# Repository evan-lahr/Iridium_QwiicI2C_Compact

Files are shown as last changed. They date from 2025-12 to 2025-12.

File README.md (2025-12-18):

Ultra-compact Qwiic (I²C) breakout for the Iridium 9603/9603N satellite modem (e.g., https://www.sparkfun.com/qwiic-iridium-9603n.html
). Built for space-constrained deployments, it integrates I²C control, power regulation, and modem support circuitry in a footprint only slightly larger than the 9603N itself—ideal for embedded field systems.

See the SparkX thread: https://community.sparkfun.com/t/qwiic-iridium-9603n-bom-firmware/67234/8

<p align="center">
  
  
</p>

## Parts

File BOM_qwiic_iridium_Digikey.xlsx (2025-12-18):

Digi-Key: Shopping Cart
Index | Quantity | Part Number | Manufacturer Part Number | Description | Customer Reference | Available | Backorder | Unit Price | Extended Price USD
1 | 1 | 399-C0603C104K5RACTUCT-ND | C0603C104K5RACTU | CAP CER 0.1UF 50V X7R 0603 | C1 | 1 | 0 | 0.08 | 0.08
2 | 1 | 490-6371-1-ND | GRM185R60J225KE26J | CAP CER 2.2UF 6.3V X5R 0603 | C2 | 1 | 0 | 0.21 | 0.21
3 | 3 | 311-1443-1-ND | CC0603KRX5R6BB105 | CAP CER 1UF 10V X5R 0603 | C3,C8,C10 | 3 | 0 | 0.1 | 0.30
4 | 1 | 445-1318-1-ND | C1608X7R1C224K080AC | CAP CER 0.22UF 16V X7R 0603 | C4 | 1 | 0 | 0.1 | 0.10
5 | 2 | 283-HV0810-2R7105-R-ND | HV0810-2R7105-R | CAP 1F -10% +30% 2.7V T/H | C5,C6 | 2 | 0 | 1.64 | 3.28
6 | 1 | 445-175223-1-ND | C1608X5R0J106K080AE | CAP CER 10UF 6.3V X5R 0603 | C7 | 1 | 0 | 0.35 | 0.35
7 | 1 | 490-GRM188R72A103KA01DCT-ND | GRM188R72A103KA01D | CAP CER 10000PF 100V X7R 0603 | C9 | 1 | 0 | 0.1 | 0.10
8 | 3 | 754-APT1608LSYCKCT-ND | APT1608LSYCK | LED YELLOW CLEAR 2SMD | D1,D2,D3 | 3 | 0 | 0.29 | 0.87
9 | 1 | SAM13255CT-ND | SS4-10-3.50-L-D-K-TR | CONN SOCKET 20POS SMD GOLD | J1 | 1 | 0 | 3 | 3.00
10 | 2 | 455-SM04B-SRSS-TBCT-ND | SM04B-SRSS-TB | CONN HEADER SMD R/A 4POS 1MM | J2,J4 | 2 | 0 | 0.5 | 1.00
11 | 1 | H9161-ND | U.FL-R-SMT(01) | CONN U.FL RCPT STR 50 OHM SMD | J7 | 0 | 1 | 1.53 | 1.53
12 | 1 | DMG3414U-7DICT-ND | DMG3414U-7 | MOSFET N-CH 20V 4.2A SOT23-3 | Q1 | 1 | 0 | 0.74 | 0.74
13 | 2 | CR0603AFX-1001EASCT-ND | CR0603AFX-1001EAS | RESA-AS 0603 1K 1% 100MW TC100 | R1,R12 | 2 | 0 | 0.1 | 0.20
14 | 3 | A129692CT-ND | CRGCQ0603F2K2 | RES 2.2K OHM 1% 1/10W 0603 | R2,R3,R13 | 3 | 0 | 0.1 | 0.30
15 | 1 | 311-4.7KGRCT-ND | RC0603JR-074K7L | RES 4.7K OHM 5% 1/10W 0603 | R4 | 1 | 0 | 0.1 | 0.10
16 | 2 | 311-10.0KHRCT-ND | RC0603FR-0710KL | RES 10K OHM 1% 1/10W 0603 | R5,R14 | 2 | 0 | 0.1 | 0.20
17 | 1 | RMCF0603FT12K0CT-ND | RMCF0603FT12K0 | RES 12K OHM 1% 1/10W 0603 | R6 | 1 | 0 | 0.1 | 0.10
18 | 1 | RMCF0603FT30K1CT-ND | RMCF0603FT30K1 | RES 30.1K OHM 1% 1/10W 0603 | R7 | 1 | 0 | 0.1 | 0.10
19 | 1 | RMCF0603FT100KCT-ND | RMCF0603FT100K | RES 100K OHM 1% 1/10W 0603 | R8 | 1 | 0 | 0.1 | 0.10
20 | 1 | 13-RL0603FR-070R012LCT-ND | RL0603FR-070R012L | RES 0.012 OHM 1% 1/10W 0603 | R9 | 1 | 0 | 0.39 | 0.39
21 | 1 | ATTINY841-SSU-ND | ATTINY841-SSU | IC MCU 8BIT 8KB FLASH 14SOIC | U1 | 1 | 0 | 1.33 | 1.33
22 | 1 | 505-LTC3225EDDB#TRMPBFCT-ND | LTC3225EDDB#TRMPBF | IC SUPERCAP CHARGER 150MA 10DFN | u2 | 1 | 0 | 7.89 | 7.89
23 | 1 | ADM4210-1AUJZ-RL7CT-ND | ADM4210-1AUJZ-RL7 | IC HOT SWAP CTRLR GP TSOT6 | U3 | 1 | 0 | 6.84 | 6.84
24 | 2 | P100HCT-ND | ERJ-3EKF1000V | RES SMD 100 OHM 1% 1/10W 0603 | R10,R11 | 2 | 0 | 0.1 | 0.20
25 | 1 | SAM8857-ND | SMA-J-P-H-ST-EM1 | CONN SMA JACK STR 50OHM EDGE MNT | SMA | 0 | 1 | 2.43 | 2.43
26 | 1 | ARF2200-ND | A-1PA-132-025B2 | COAX CBL U.FL AMC-U.FL AMC 0.9" | AMPH_CABLE | 1 | 0 | 6.89 | 6.89
27 | 2 | 732-7103-6-ND | 9774060243R | REFLOW STANDOFF | NA | 1 | 0 | 1.01 | 1.01

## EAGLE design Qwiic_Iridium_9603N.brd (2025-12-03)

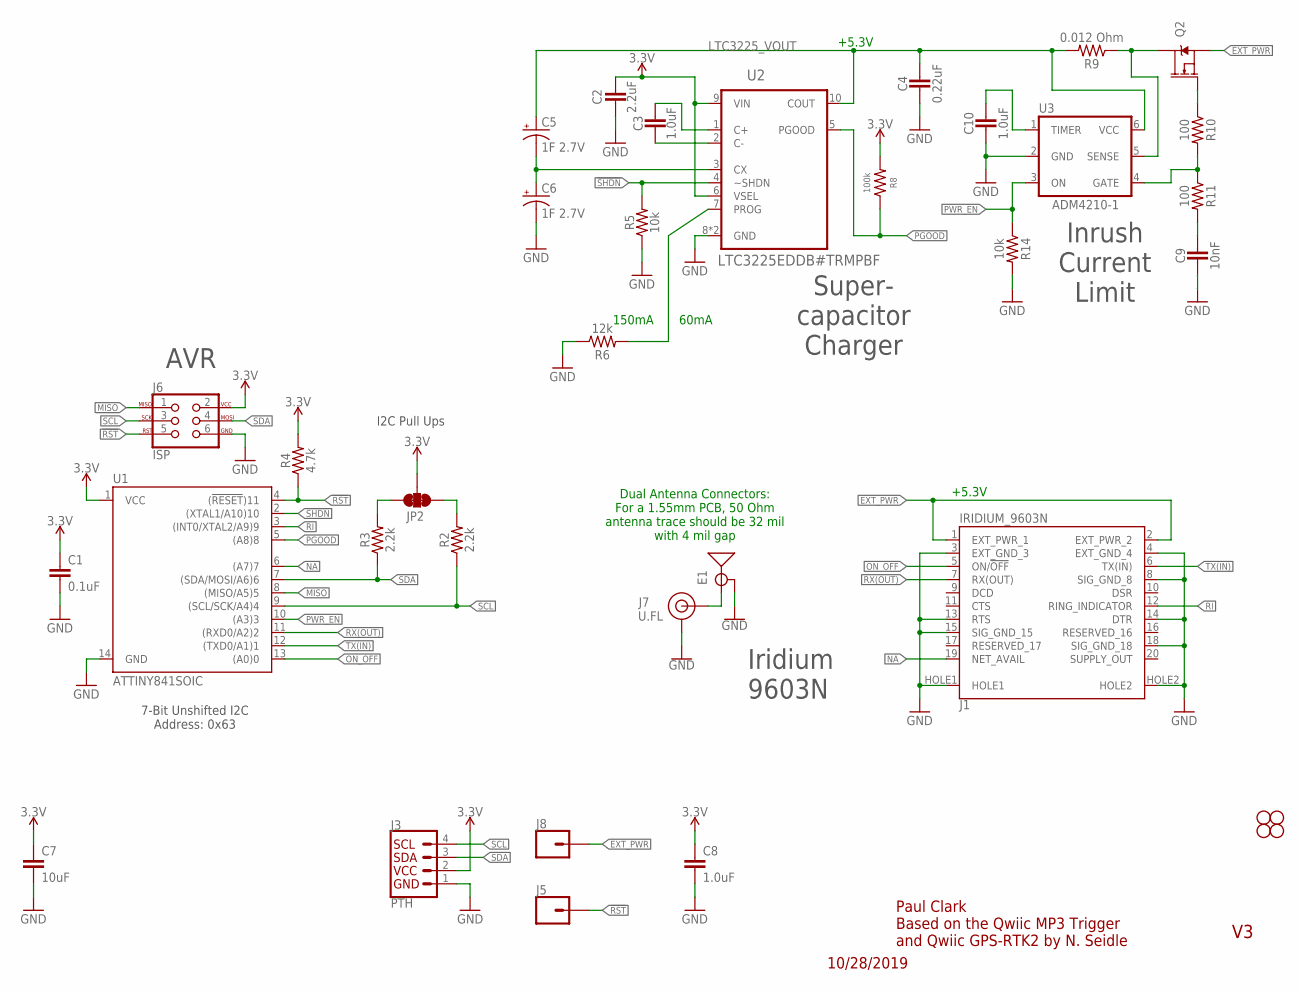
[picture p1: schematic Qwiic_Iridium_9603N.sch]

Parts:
C1: 0.1uF; 0603
C2: 2.2uF; 0603
C3, C8, C10: 1.0uF; 0603
C4: 0.22uF; 0603
C5, C6: 1F 2.7V; CPOL-RADIAL-1F-2.7V
C7: 10uF; 0603
C9: 10nF; 0603
E1: ANTENNA-GROUNDEDEDGE_SMA; SMA-EDGE
J1: IRIDIUM_9603N
J3: PTH; 1X04_1MM_RA
J5, J8: CONN_01PTH_NO_SILK_YES_STOP; 1X01_NO_SILK
J6: ISP; 2X3_TEST_POINTS
J7: U.FL
JP2: JUMPER-SMT_3_2-NC_TRACE_SILK; SMT-JUMPER_3_2-NC_TRACE_SILK
JP3, JP4, JP9, JP10: STAND-OFF
Q2: 5.8A/30V/35mΩ; SOT23-3
R2, R3: 2.2k; 0603
R4: 4.7k; 0603
R5, R14: 10k; 0603
R6: 12k; 0603
R8: 100k; 0603
R9: 0.012 Ohm; 0603
R10, R11: 100; 0603
U1: ATTINY841SOIC; ATTINY841
U2: LTC3225EDDB#TRMPBF; DFN300X200-10L
U3: ADM4210-1; TSOT6

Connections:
3.3V: C1.1, C2.1, C7.1, C8.1, J3.2 (VCC), J6.2, JP2.2, R4.2, R8.2, U1.1 (VCC), U2.6 (VSEL), U2.9 (VIN)
!RST: J5.1, J6.5, R4.1, U1.4 ((!RESET!)11)
!SHDN: R5.2, U1.2 ((XTAL1/A10)10), U2.4 (~SHDN)
EXT_PWR: J1.1 (EXT_PWR_1), J1.2 (EXT_PWR_2), J8.1, Q2.2 (S)
GND: C1.2, C2.2, C4.2, C6.-, C7.2, C8.2, C9.2, C10.2, E1.GND@0 (GND), E1.GND@1 (GND), E1.GND@2 (GND), E1.GND@3 (GND), J1.3 (EXT_GND_3), J1.4 (EXT_GND_4), J1.8 (SIG_GND_8), J1.13 (RTS), J1.14 (DTR), J1.15 (SIG_GND_15), J1.18 (SIG_GND_18), J1.HOLE1, J1.HOLE2, J3.1 (GND), J6.6, J7.1 (GND), J7.2 (GND), R5.1, R6.1, R14.2, U1.14 (GND), U2.8 (GND), U2.11 (GND), U3.2 (GND)
LTC3225_VOUT: C4.1, C5.+, R9.2, U2.10 (COUT), U3.6 (VCC)
MISO: J6.1, U1.8 ((MISO/A5)5)
unnamed: C5.-, C6.+, U2.3 (CX)
unnamed: R6.2, U2.7 (PROG)
unnamed: E1.SIG (SIGNAL), J7.FEED (SIGNAL)
unnamed: Q2.3 (D), R9.1, U3.5 (SENSE)
unnamed: C3.2, U2.2 (C-)
unnamed: C3.1, U2.1 (C+)
unnamed: Q2.1 (G), R10.1
unnamed: R10.2, R11.1, U3.4 (GATE)
unnamed: C9.1, R11.2
unnamed: C10.1, U3.1 (TIMER)
NA: J1.19 (NET_AVAIL), U1.6 ((A7)7)
ON_OFF: J1.5 (ON/!OFF!), U1.13 ((A0)0)
PGOOD: R8.1, U1.5 ((A8)8), U2.5 (PGOOD)
PWR_EN: R14.1, U1.10 ((A3)3), U3.3 (ON)
RI: J1.12 (RING_INDICATOR), U1.3 ((INT0/XTAL2/A9)9)
RX(OUT): J1.7 (RX(OUT)), U1.11 ((RXD0/A2)2)
SCL: J3.4 (SCL), J6.3, R2.1, U1.9 ((SCL/SCK/A4)4)
SCL_PU1: JP2.1, R2.2
SDA: J3.3 (SDA), J6.4, R3.1, U1.7 ((SDA/MOSI/A6)6)
SDA_PU1: JP2.3, R3.2
TX(IN): J1.6 (TX(IN)), U1.12 ((TXD0/A1)1)

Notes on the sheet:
Paul Clark Based on the Qwiic MP3 Trigger and Qwiic GPS-RTK2 by N. Seidle
7-Bit Unshifted I2C Address: 0x63
I2C Pull Ups
AVR
+5.3V
150mA
60mA
Super- capacitor Charger
Iridium 9603N
Dual Antenna Connectors: For a 1.55mm PCB, 50 Ohm antenna trace should be 32 mil with 4 mil gap
Inrush Current Limit
10/28/2019

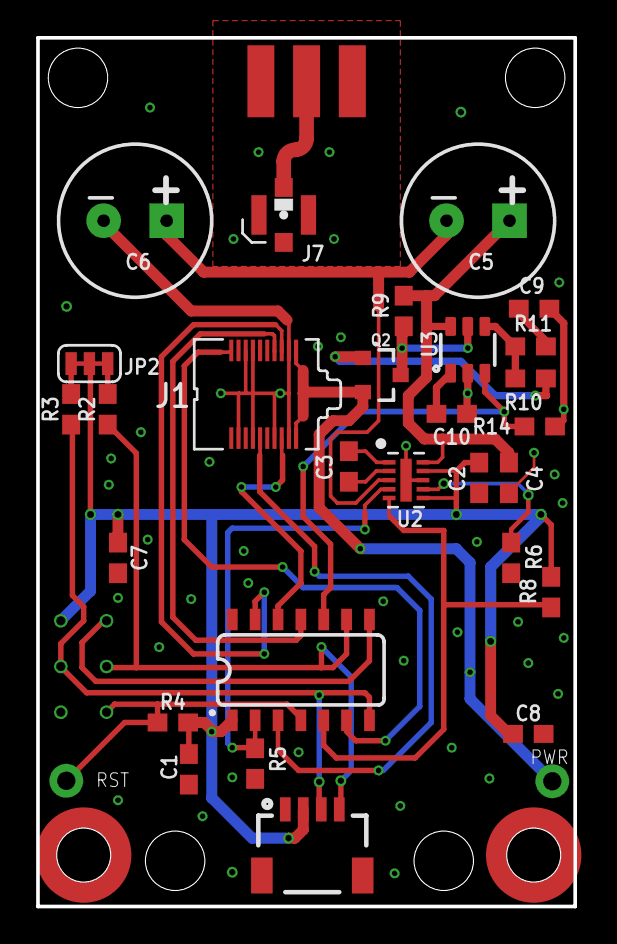
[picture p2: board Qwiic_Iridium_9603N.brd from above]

Board: 2 copper layers, 29.8 x 48.3 mm, 36 parts (1 on the bottom side), 28 nets.

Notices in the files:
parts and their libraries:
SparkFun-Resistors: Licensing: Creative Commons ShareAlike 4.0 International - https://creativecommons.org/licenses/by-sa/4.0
